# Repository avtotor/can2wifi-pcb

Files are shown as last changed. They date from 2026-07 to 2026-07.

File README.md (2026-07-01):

# can2wifi-pcb

Custom PCB for the [can2wifi](https://github.com/avtotor/can2wifi) firmware — a
**CAN → WiFi bridge** on ESP32-S3 that plugs into a vehicle OBD-II port, reads the
CAN bus via TWAI and streams frames over WiFi (Telnet :23, GVRET / SavvyCAN) and
UART. Targeted at **mass production via JLCPCB** (full PCBA).

> ⚠️ **Status: engineering draft — NOT yet fab-ready.** The schematic is complete
> and ERC-clean, footprints are assigned, components are placed and ground pours
> added. **Copper routing is NOT done** and several values need datasheet
> verification. See [Before you order](#before-you-order). Open the project in
> KiCad and finish/review it before sending anywhere.

## Design decisions

| Topic | Choice |
|---|---|
| Power | **12 V only** from OBD-II (pin 16) → DC-DC buck → 5 V → LDO → 3.3 V. USB is data-only. |
| Manufacturing | Full PCBA at JLCPCB (Gerber + BOM + CPL, LCSC parts). |
| Vehicle connector | **OBD-II J1962 male**, board-mounted, THT (hand-solder). |
| Protection | Extended: reverse-polarity, 12 V load-dump TVS, CAN common-mode choke + TVS, USB ESD. |
| CAN transceiver | **TJA1051T/3** (3.3 V VIO) instead of TJA1050 — removes the 1k/2k divider and the marginal 5 V TXD threshold. Firmware-compatible. |
| USB | CH340C USB-UART on UART0 (GPIO43/44) + dual-transistor auto-program. Native USB unavailable (GPIO20 used by CAN). |
| Board | 70 × 52 mm, 2-layer FR4 1.6 mm, GND pours both sides. |

## Architecture

```mermaid
flowchart TD
    OBD["OBD-II 12V"] --> F1["F1 PTC"] --> TVS["TVS SMBJ24A"] --> D2["D2 SS56 rev-pol"] --> V12["+12V"]
    V12 --> U4["U4 LM5164 buck 100V"] --> V5["+5V"]
    V5 --> U5["U5 AMS1117"] --> V3["+3V3"]
    V3 --> U1["U1 ESP32-S3"]
    USB["USB-C"] --> D4["D4 USBLC6 ESD"] -->|D+/D-| U3["U3 CH340C"]
    U3 -->|UART0| U1
    U3 -->|DTR/RTS| Q["Q1/Q2"] -->|EN / IO0| U1
    U1 -->|GPIO21/20| U2["U2 TJA1051"] --> L2["L2 CMC"] --> D3["D3 TVS"] --> CAN["CANH/CANL → OBD 6/14"]
```

## Signal map (from firmware)

| Net | ESP32-S3 pin | Notes |
|---|---|---|
| CAN_TX | IO21 | → TJA1051 TXD |
| CAN_RX | IO20 (module pin 14 "USB_D+") | ← TJA1051 RXD |
| LED_STAT | IO2 | active-high status LED (D7) |
| ESP_TX | TXD0 / IO43 | → CH340 RXD |
| ESP_RX | RXD0 / IO44 | ← CH340 TXD |
| EN | EN | RST button + RC + Q1 |
| IO0 | IO0 | BOOT button + Q2 |

> Native USB (GPIO19/20) is sacrificed: GPIO20 is the CAN RX pin, so programming
> goes through the CH340C on UART0. **On the bench, apply 12 V while flashing**
> (USB does not power the board). Optional DNP diode **D5** (VBUS→+5V) can be
> populated to power the board from USB for bench work.

## BOM (51 placements)

Assembly BOM with LCSC part numbers: [doc/can2wifi-pcb-bom-jlcpcb.csv](doc/can2wifi-pcb-bom-jlcpcb.csv)
(JLCPCB columns: Comment / Designator / Footprint / LCSC Part #). Plain BOM:
[doc/can2wifi-pcb-bom.csv](doc/can2wifi-pcb-bom.csv).

**44 of 51 placements have a verified in-stock LCSC number.** Still TBD (pick
before ordering): **D6/D7** LEDs (green/blue 0603), **F1** PPTC fuse (0.5 A 1812),
**R4** 31.6 k (set by buck feedback — verify), **R8** 120 Ω (DNP, not fitted),
**SW1/SW2** tactile buttons (match the PTS645 footprint), **J1** OBD-II connector
(hand-soldered, not JLCPCB-assembled).

| Ref | Value | Footprint |
|---|---|---|
| U1 | ESP32-S3-WROOM-1-N16R8 | RF_Module:ESP32-S3-WROOM-1 |
| U2 | TJA1051T/3 | SOIC-8 |
| U3 | CH340C | SOIC-16 |
| U4 | LM5164DDA (100 V sync buck) | SOIC-8-1EP ThermalVias |
| U5 | AMS1117-3.3 | SOT-223 |
| Q1, Q2 | MMBT3904 | SOT-23 |
| D1 | SMBJ24A (load-dump TVS) | SMB |
| D2 | SS34 (reverse-polarity, C115205) | SMA |
| D3 | PESD2CAN (CAN TVS) | SOT-23 |
| D4 | USBLC6-2SC6 (USB ESD) | SOT-23-6 |
| D5 | SS34 — **DNP** (USB→5V bench) | SMA |
| D6/D7 | Power / Status LED | 0603 |
| L1 | 33 µH (buck) | 12×12 mm |
| L2 | CAN common-mode choke | Coilcraft 1812CAN |
| F1 | PTC 0.5 A | 1812 |
| J1 | OBD-II J1962 male | can2wifi:OBD2_J1962_Male (custom) |
| J2 | USB-C 2.0 | HRO TYPE-C-31-M-12 |
| R1/R3 100k, R2 13k, R4 31.6k | LM5164 UVLO/RON/FB | 0603 |
| R5–R7 10k | EN/IO0 pull-ups | 0603 |
| R8 120Ω — **DNP** | CAN termination (bus already terminated) | 0805 |
| R9/R10 5.1k | USB-C CC | 0603 |
| R11/R12 1k | LED series | 0603 |
| R13 0Ω | CH340 V3↔3V3 link | 0603 |
| SW1/SW2 | RST / BOOT | PTS645 |
| C1–C17 | decoupling / bulk / buck | 0603/0805/1210 |

## Before you order

This board **must be finished and reviewed in KiCad** first. Checklist:

1. **Route the board.** No copper traces exist yet. Either install Java + the
   Freerouting JAR and run the MCP `autoroute`, or route manually in Pcbnew.
   Gerbers/CPL are only meaningful after routing.
2. **Clean up placement.** Auto-placement left courtyard overlaps (esp. around U1
   — the WROOM-1 footprint reserves a large keep-out/antenna area). Re-arrange so
   the ESP32 antenna sits over a board edge with copper keep-out beneath it.
3. **Verify the LM5164 buck values** against the TI datasheet / WEBENCH:
   `R3 (RON)` switching frequency, `L1` inductor, `R4/R5` feedback divider for
   5.0 V, `C4` feed-forward, input/output caps. These are reference-style
   placeholders, not silicon-verified.
4. **Verify the J1962 footprint** (`can2wifi.pretty/OBD2_J1962_Male`) against the
   exact OBD-II male connector you buy — pin pitch, row spacing and mounting holes
   are a generic 2×8 layout and will differ per part.
5. **Finish LCSC assignment** — 44/51 done; assign the 7 TBD lines (LEDs, fuse,
   buttons, R4 31.6k) and regenerate the BOM + CPL for assembly.
6. **Confirm the USB-C MPN** matches the `HRO TYPE-C-31-M-12` footprint.
7. Run **DRC** until clean, refill zones, then export Gerbers, drill, BOM and CPL.

## Files

| Path | Contents |
|---|---|
| `can2wifi-pcb.kicad_sch` | Schematic (ERC-clean: 0 errors) |
| `can2wifi-pcb.kicad_pcb` | Board: outline, placement, GND pours (unrouted) |
| `can2wifi.pretty/` | Custom J1962 footprint |
| `doc/can2wifi-pcb-schematic.pdf` | Schematic PDF |
| `doc/can2wifi-pcb-bom.csv` | BOM (grouped by value) |

## License

Proprietary — see [LICENSE](LICENSE).

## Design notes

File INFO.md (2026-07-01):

# INFO.md — назначение каждого файла проекта

Это **аппаратный проект KiCad**: печатная плата моста CAN→WiFi OBD-II
[can2wifi](https://github.com/avtotor/can2wifi) на ESP32-S3. Здесь описан каждый файл
репозитория: что это, зачем нужен и можно ли его удалять.

Принцип:
- **Source of truth** — данные, созданные вручную. Их удаление уничтожает работу,
  которую невозможно восстановить. **Удалять нельзя.**
- **Генерируемое / локальное** — то, что KiCad или тулчейн создаёт из source of truth,
  либо настройки конкретной машины. Удалять безопасно — пересоздаётся.

---

## Source of truth — УДАЛЯТЬ НЕЛЬЗЯ

Эти файлы определяют плату. Потеря любого = потеря невосстановимой работы.

| Файл | Что это | Зачем нужен |
|---|---|---|
| `can2wifi-pcb.kicad_sch` | **Схема.** Компоненты, цепи, номиналы, вся электрическая часть. | Электрический проект. Всё остальное (нетлист, BOM, связи на плате) выводится из неё. ERC-clean. |
| `can2wifi-pcb.kicad_pcb` | **Разводка платы.** Контур, размещение, трассировка меди, полигоны GND, переходные. | Физическая плата — именно это идёт в производство. Здесь часы размещения и трассировки; ниоткуда не пересоздаётся. |
| `can2wifi-pcb.kicad_pro` | **Файл проекта.** Design rules, net-классы, зазоры, стек слоёв, настройки плотов. | Связывает схему и плату, хранит правила, по которым проверяет DRC. Без него KiCad не откроет проект. |
| `can2wifi.pretty/OBD2_J1962_Male.kicad_mod` | **Кастомный футпринт** разъёма OBD-II J1962 (male). | Единственный футпринт не из стандартных библиотек KiCad. Плата на него ссылается; удаление ломает разъём J1962 на PCB. |
| `fp-lib-table` | **Таблица библиотек футпринтов.** Регистрирует локальную библиотеку `can2wifi.pretty`. | Без неё KiCad не найдёт кастомный футпринт J1962 выше. |

## Документация / конфиг — оставляем

| Файл | Что это | Зачем нужен |
|---|---|---|
| `README.md` | Исходный замысел и обзор проекта. | Человекочитаемое описание целей. Внимание: может отставать от реального состояния платы — для текущей разводки доверяй файлам `.kicad_*`. |
| `INFO.md` | Этот файл. | Инвентаризация всех файлов и их назначения. |
| `CLAUDE.md` | Инструкции для Claude Code по этому репозиторию (workflow, подводные камни, конвенции). | Хранит накопленные знания о причудах MCP-бэкенда KiCad. Для сборки платы не обязателен, но дорого восстанавливать. |
| `LICENSE` | **Проприетарная** лицензия. | Юридические условия проекта. Не заменять на open-source. |
| `.gitignore` | Правила игнорирования git. | Не пускает генерируемые/локальные файлы (fab, нетлист, lock-файлы, бэкапы) в систему контроля версий. Удалишь — мусор вернётся в репозиторий. |

---

## Генерируемое / локальное — УДАЛЯТЬ БЕЗОПАСНО (пересоздаётся)

Ничего из этого нет в репозитории (в `.gitignore`), и большинства нет на диске — всё
производится из source of truth (или это настройки машины). Пересоздаётся из KiCad по
необходимости.

| Файл | Что это | Чем пересоздать |
|---|---|---|
| `doc/can2wifi-pcb-schematic.pdf` | PDF-плот схемы (просмотр без KiCad). | KiCad: плот схемы в PDF (или MCP `export_schematic_pdf`). |
| `doc/can2wifi-pcb-pcb.pdf` | PDF-плот платы (просмотр без KiCad). | KiCad: плот платы в PDF (или MCP `export_pcb_pdf`). |
| `can2wifi-pcb.net` | Нетлист, выгруженный из схемы. | KiCad: экспорт нетлиста (или MCP `export_netlist`). |
| `fab/can2wifi-pcb-gerbers.zip` | Пакет gerber + drill для производства (JLCPCB). | KiCad plot / MCP `export_gerbers` + `export_drill`. |
| `fab/can2wifi-pcb-bom-jlcpcb.csv` | Bill of Materials в формате JLCPCB. | MCP `export_bom` (исключить DNP: D5, R8). |
| `fab/can2wifi-pcb-cpl-jlcpcb.csv` | Размещение компонентов (pick-and-place) для PCBA. | MCP `export_pos` (CPL). |
| `can2wifi-pcb.kicad_prl` | Локальное состояние проекта KiCad (панели, последний вид, локальные настройки). | KiCad пересоздаёт при открытии. Привязано к машине. |
| `.claude/settings.local.json` | Локальные настройки/разрешения Claude Code для этой машины. | К плате отношения не имеет; специфично для окружения. |

> Весь каталог `fab/` — это генерируемый вывод: **развести плату → DRC-clean →
> экспортировать fab-файлы**. Это поставка на производство, а не source.

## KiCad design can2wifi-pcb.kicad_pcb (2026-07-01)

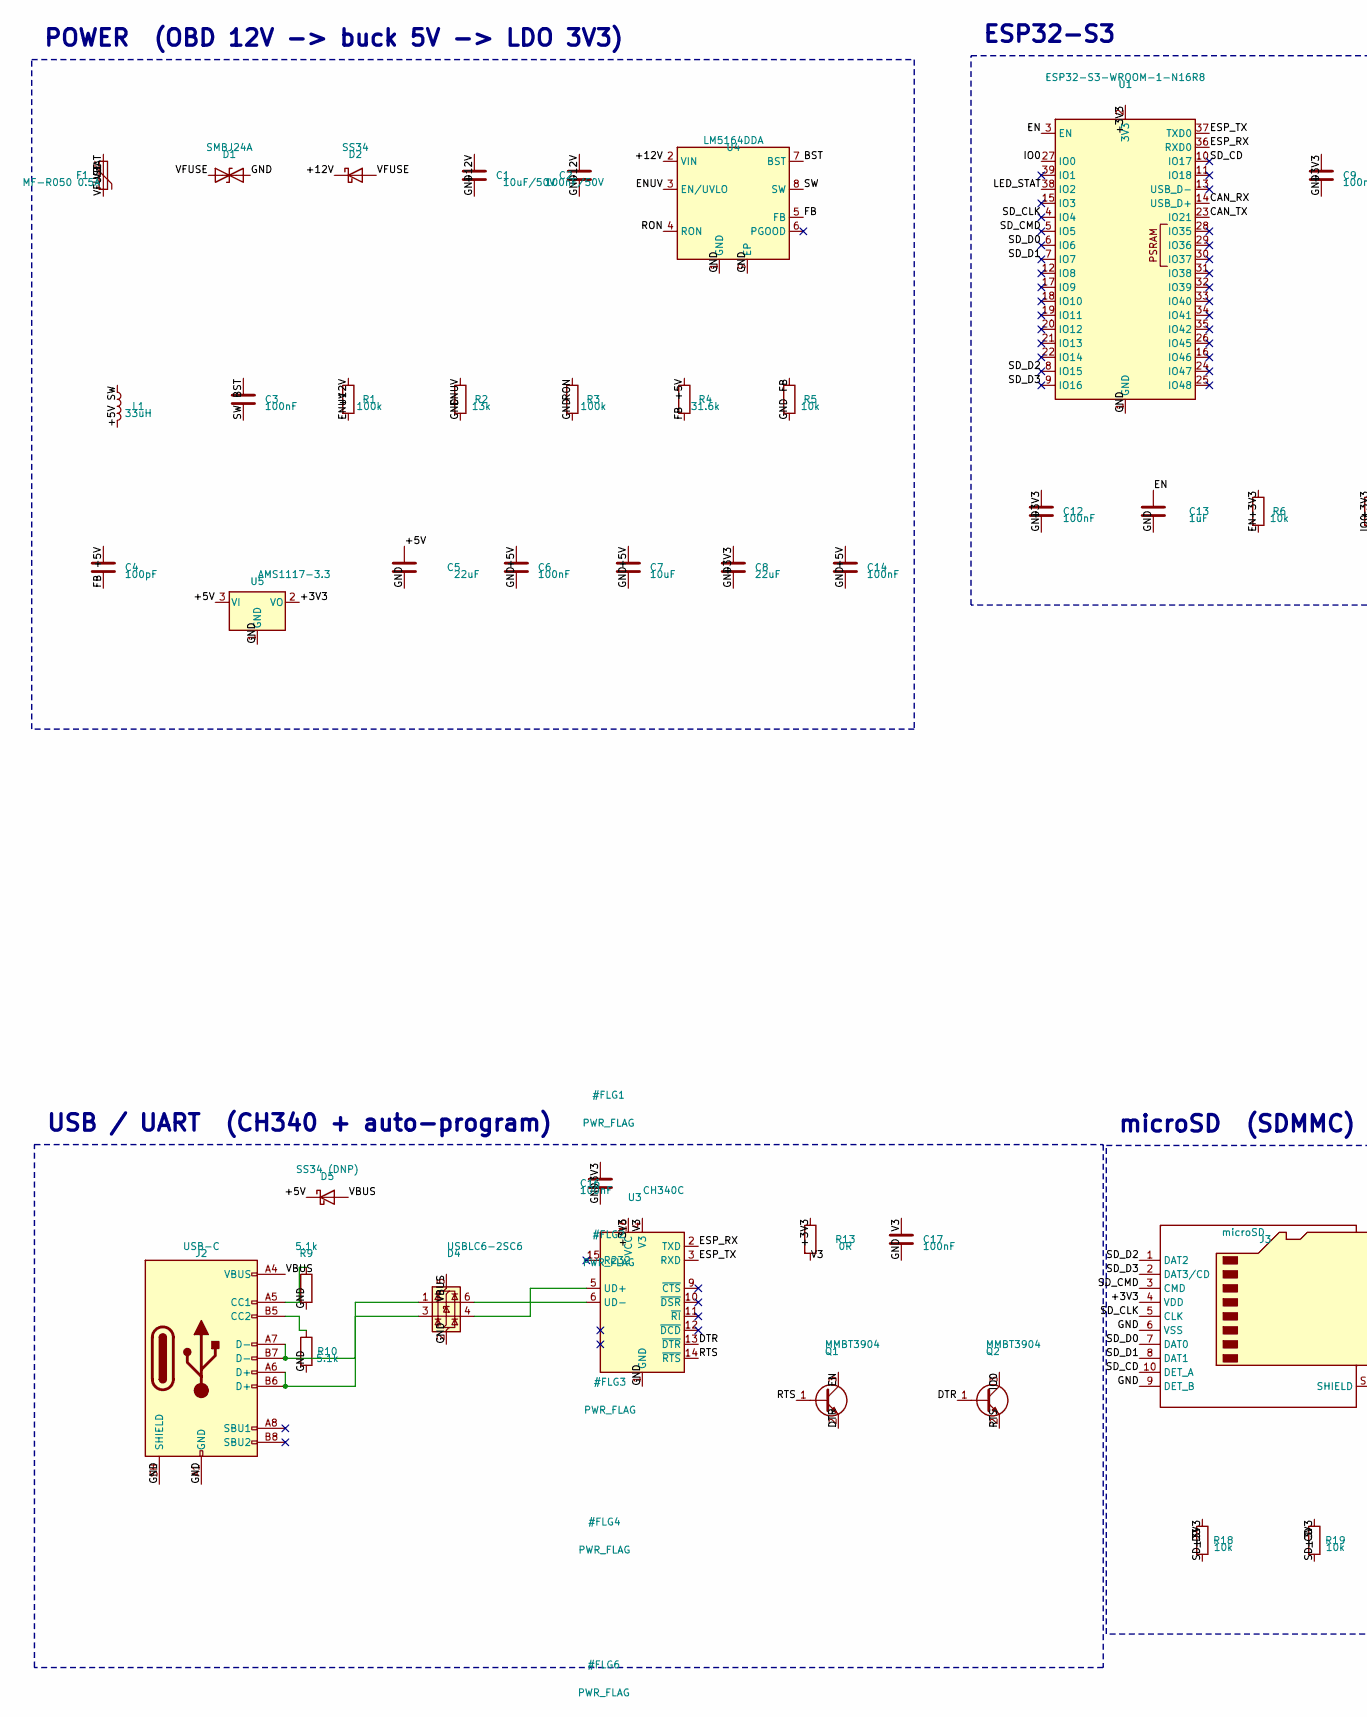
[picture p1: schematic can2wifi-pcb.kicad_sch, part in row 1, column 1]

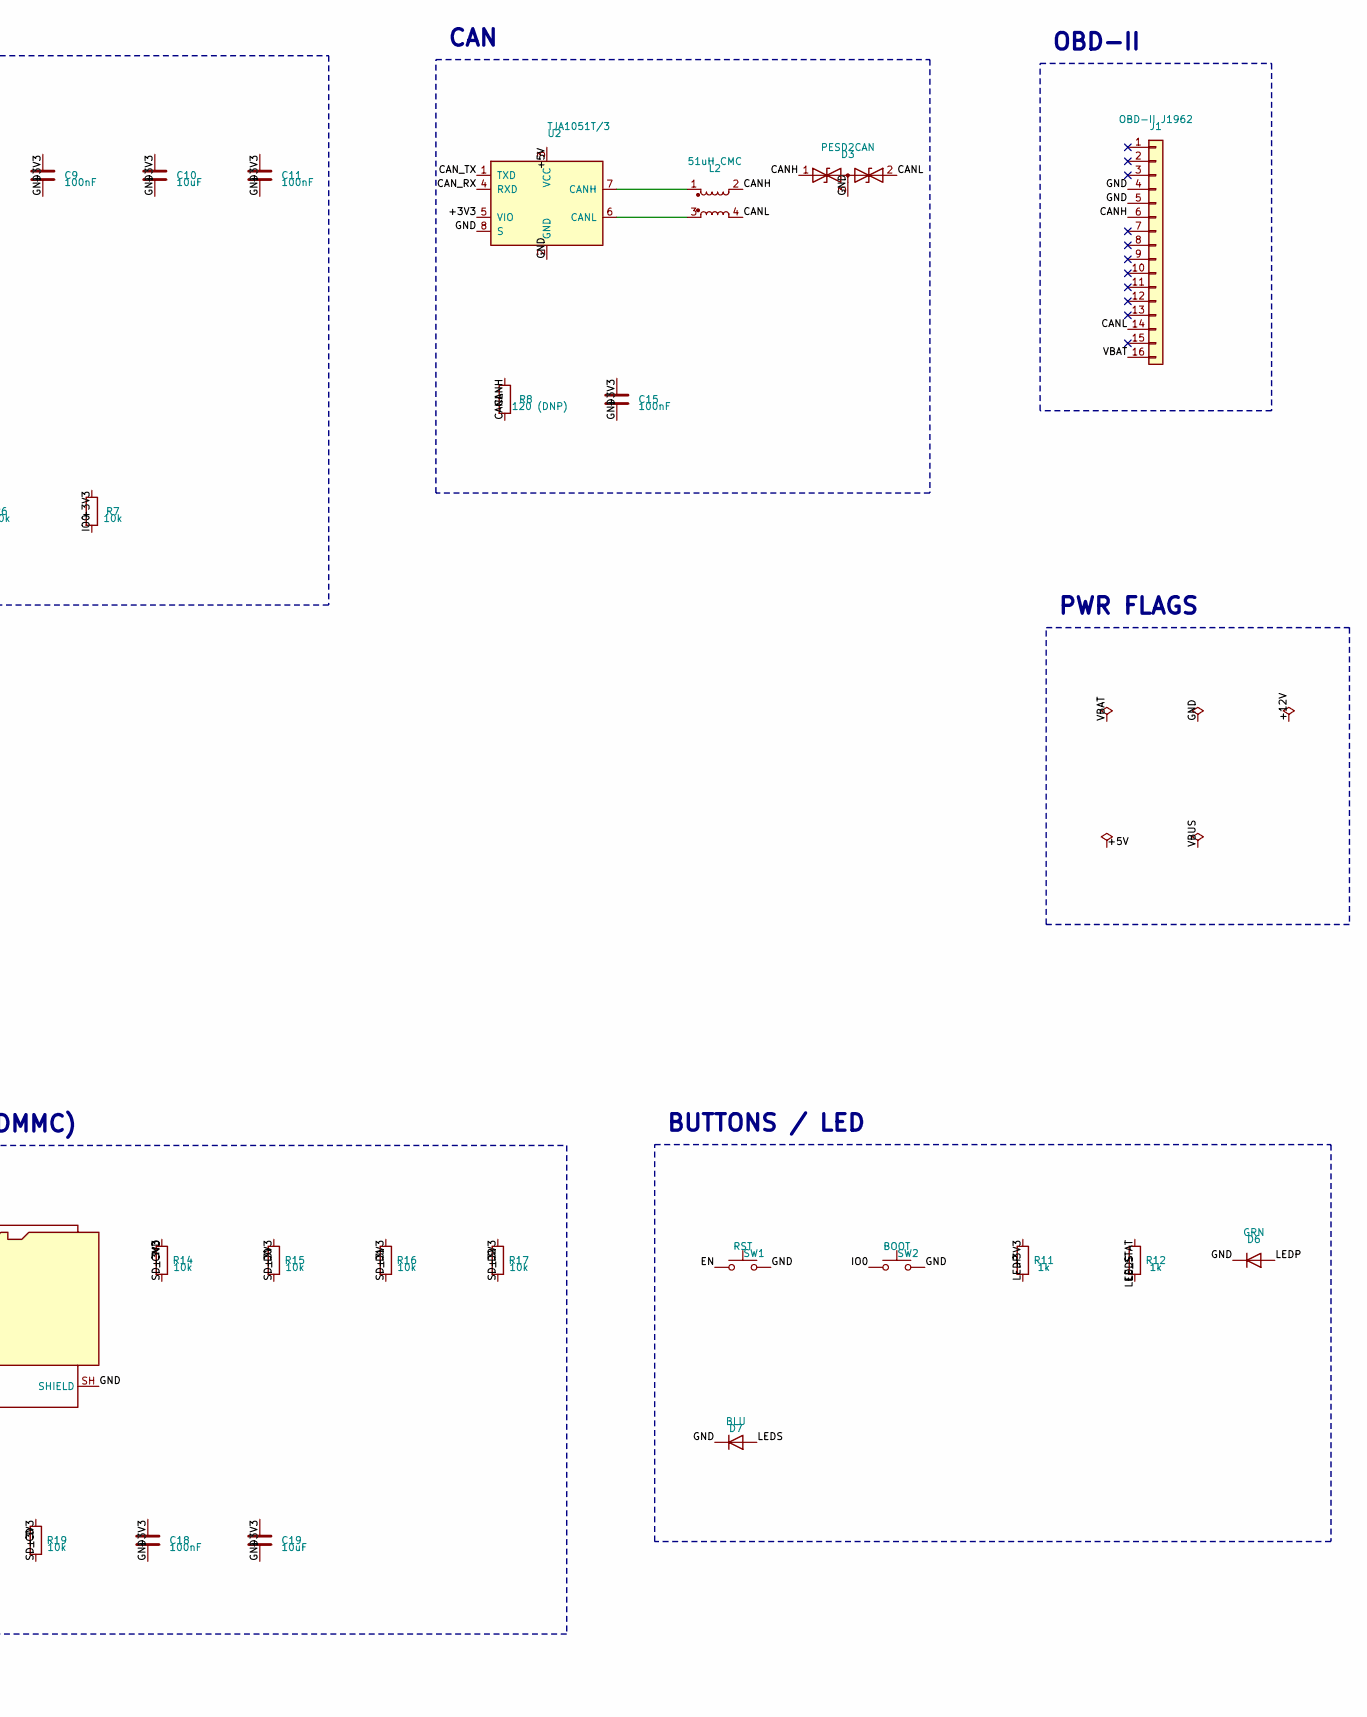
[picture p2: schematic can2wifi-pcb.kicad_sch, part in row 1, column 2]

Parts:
C1: 10uF/50V; C_1210_3225Metric; LCSC C116808
C2: 100nF/50V; C_0603_1608Metric; LCSC C14663
C3, C6, C9, C11, C12, C14, C15, C16, C17: 100nF; C_0603_1608Metric; LCSC C14663
C4: 100pF; C_0603_1608Metric; LCSC C14858
C5, C8: 22uF; C_0805_2012Metric; LCSC C109314
C7, C10: 10uF; C_0805_2012Metric; LCSC C105505
C13: 1uF; C_0603_1608Metric; LCSC C105524
C18: 100nF; C_0603_1608Metric
C19: 10uF; C_0805_2012Metric
D1: SMBJ24A; D_SMB; LCSC C123819
D2: SS34; D_SMA; LCSC C115205
D3: PESD2CAN; SOT-23; LCSC C2687131
D4: USBLC6-2SC6; SOT-23-6; LCSC C19170930
D5: SS34 (DNP); D_SMA; LCSC C115205
D6: GRN; LED_0603_1608Metric
D7: BLU; LED_0603_1608Metric
F1: MF-R050 0.5A; R_1812_4532Metric
J1: OBD-II J1962; OBD2_J1962_Male
J2: USB-C; USB_C_Receptacle_HRO_TYPE-C-31-M-12; LCSC C165948
J3: microSD; microSD_HC_Hirose_DM3AT-SF-PEJM5
L1: 33uH; L_12x12mm_H8mm; LCSC C127788
L2: 51uH CMC; L_CommonModeChoke_Coilcraft_1812CAN; LCSC C49230370
Q1, Q2: MMBT3904; SOT-23; LCSC C111113
R1, R3: 100k; R_0603_1608Metric; LCSC C25803
R2: 13k; R_0603_1608Metric; LCSC C22797
R4: 31.6k; R_0603_1608Metric
R5, R6, R7: 10k; R_0603_1608Metric; LCSC C25804
R8: 120 (DNP); R_0805_2012Metric
R9, R10: 5.1k; R_0603_1608Metric; LCSC C23186
R11, R12: 1k; R_0603_1608Metric; LCSC C21190
R13: 0R; R_0603_1608Metric; LCSC C21189
R14, R15, R16, R17, R18, R19: 10k; R_0603_1608Metric
SW1: RST; SW_SPST_PTS645Sx43SMTR92
SW2: BOOT; SW_SPST_PTS645Sx43SMTR92
U1: ESP32-S3-WROOM-1-N16R8; ESP32-S3-WROOM-1; LCSC C2913202
U2: TJA1051T/3; SOIC-8_3.9x4.9mm_P1.27mm; LCSC C1850231
U3: CH340C; SOIC-16_3.9x9.9mm_P1.27mm; LCSC C84681
U4: LM5164DDA; SOIC-8-1EP_3.9x4.9mm_P1.27mm_EP2.41x3.3mm_ThermalVias; LCSC C477928
U5: AMS1117-3.3; SOT-223-3_TabPin2; LCSC C18164485

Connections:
+3V3: C8.1, C9.1, C10.1, C11.1, C12.1, C15.1, C16.1, C18.1, C19.1, J3.4 (VDD), R6.1, R7.1, R11.1, R13.1, R14.1, R15.1, R16.1, R17.1, R18.1, R19.1, U1.2 (3V3), U2.5 (VIO), U3.16 (VCC), U5.2 (VO)
+5V: C4.1, C5.1, C6.1, C7.1, C14.1, D5.1 (K), L1.2, R4.1, U2.3 (VCC), U5.3 (VI)
+12V: C1.1, C2.1, D2.1 (K), R1.1, U4.2 (VIN)
BST: C3.1, U4.7 (BST)
CANH: D3.1 (A1), J1.6, L2.2, R8.1
CANH_T: L2.1, U2.7 (CANH)
CANL: D3.2 (A2), J1.14, L2.4, R8.2
CANL_T: L2.3, U2.6 (CANL)
CAN_RX: U1.14 (USB_D+), U2.4 (RXD)
CAN_TX: U1.23 (IO21), U2.1 (TXD)
CC1: J2.A5 (CC1), R9.1
CC2: J2.B5 (CC2), R10.1
DTR: Q1.2 (E), Q2.1 (B), U3.13 (~DTR)
EN: C13.1, Q1.3 (C), R6.2, SW1.1, U1.3 (EN)
ENUV: R1.2, R2.1, U4.3 (EN/UVLO)
ESP_RX: U1.36 (RXD0), U3.2 (TXD)
ESP_TX: U1.37 (TXD0), U3.3 (RXD)
FB: C4.2, R4.2, R5.1, U4.5 (FB)
GND: C1.2, C2.2, C5.2, C6.2, C7.2, C8.2, C9.2, C10.2, C11.2, C12.2, C13.2, C14.2, C15.2, C16.2, C17.2, C18.2, C19.2, D1.2 (A2), D3.3 (common), D4.2 (GND), D6.1 (K), D7.1 (K), J1.4, J1.5, J2.A1 (GND), J2.A12 (GND), J2.B1 (GND), J2.B12 (GND), J2.SH (SHIELD), J3.6 (VSS), J3.9 (DET_B), J3.SH (SHIELD), R2.2, R3.2, R5.2, R9.2, R10.2, SW1.2, SW2.2, U1.1 (GND), U1.40 (GND), U1.41 (GND), U2.2 (GND), U2.8 (S), U3.1 (GND), U4.1 (GND), U4.9 (EP), U5.1 (GND)
IO0: Q2.3 (C), R7.2, SW2.1, U1.27 (IO0)
LEDP: D6.2 (A), R11.2
LEDS: D7.2 (A), R12.2
LED_STAT: R12.1, U1.38 (IO2)
RON: R3.1, U4.4 (RON)
RTS: Q1.1 (B), Q2.2 (E), U3.14 (~RTS)
SD_CD: J3.10 (DET_A), R19.2, U1.10 (IO17)
SD_CLK: J3.5 (CLK), U1.4 (IO4)
SD_CMD: J3.3 (CMD), R14.2, U1.5 (IO5)
SD_D0: J3.7 (DAT0), R15.2, U1.6 (IO6)
SD_D1: J3.8 (DAT1), R16.2, U1.7 (IO7)
SD_D2: J3.1 (DAT2), R17.2, U1.8 (IO15)
SD_D3: J3.2 (DAT3/CD), R18.2, U1.9 (IO16)
SW: C3.2, L1.1, U4.8 (SW)
USBC_DM: D4.3 (I/O2), J2.A7 (D-), J2.B7 (D-)
USBC_DP: D4.1 (I/O1), J2.A6 (D+), J2.B6 (D+)
V3: C17.1, R13.2, U3.4 (V3)
VBAT: F1.1, J1.16
VBUS: D4.5 (VBUS), D5.2 (A), J2.A4 (VBUS), J2.A9 (VBUS), J2.B4 (VBUS), J2.B9 (VBUS)
VFUSE: D1.1 (A1), D2.2 (A), F1.2

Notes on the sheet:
POWER (OBD 12V -> buck 5V -> LDO 3V3)
ESP32-S3
CAN
OBD-II
USB / UART (CH340 + auto-program)
microSD (SDMMC)
BUTTONS / LED
PWR FLAGS

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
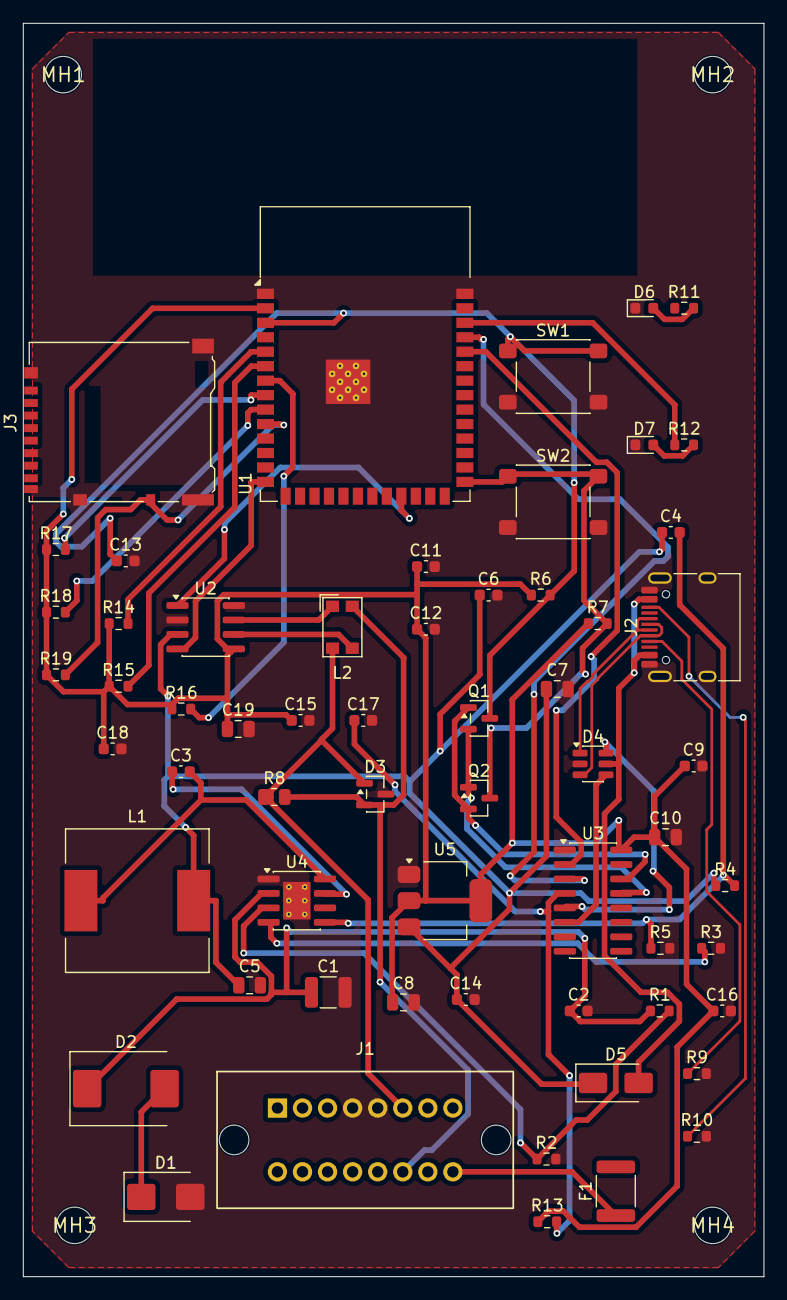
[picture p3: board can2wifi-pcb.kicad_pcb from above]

Board: 2 copper layers, 65.0 x 110.0 mm, 64 parts (0 on the bottom side), 41 nets.

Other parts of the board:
MH1, MH2, MH3, MH4: MountingHole_3.2mm
